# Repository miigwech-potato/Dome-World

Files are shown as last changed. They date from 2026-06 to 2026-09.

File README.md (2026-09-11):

# Cat Dome — a bermed, corbelled shelter with a wasp-cell wall

A printable test structure for the Canatara stage: small enough to build, cheap
enough to fail, and it tests the one thing the envelope claim depends on —
whether an unheated, self-ventilating, earth-sheltered shell stays liveable
through a Sarnia winter.

## What it is

- Interior: **440 mm diameter × 320 mm high**. Deliberately small. A cat heats
  the space with its own body; a large shelter is a cold shelter.
- Two openings, opposite each other, 150 mm wide. Cats will not use a shelter
  they can be cornered in.
- Wall: **5 mm skin + 16 mm hexagonal cell core + 5 mm skin = 26 mm.**
- Five corbelled tiers, eight segments each: **40 printed pieces** plus the
  chimney collar.
- Lower two tiers are bermed. The top three stand proud.

## The two findings that changed the design

**1. Print the segments flat, not standing.**

A dome printed in its final orientation has a near-horizontal apex — the top
tier came out at 64° of overhang and would need support. Laid flat on the bed,
each tier segment is a curved plate and the problem disappears. Every segment
fits within 200 × 200 mm.

This is also why the wall core is hexagonal cells rather than one continuous
air gap: laid flat, hex cell walls stand vertical on the bed and self-support.
A continuous cavity would sag.

**2. Do not put the wool in the cells.**

| core | R-value (m²K/W) | loss at ΔT=30K |
|---|---|---|
| air-filled cells | 0.692 | 13.2 W |
| wool-filled cells | 0.477 | 19.1 W |

Still air conducts at about 0.026 W/m·K. Wool is about 0.040. In a sealed 16 mm
cell the air is not convecting, so it is already the better insulator — packing
wool in makes the wall roughly 45% worse.

**Wool belongs on the inside face**, as a lining: contact comfort, moisture
buffering, and something to nest in. The cells stay empty.

## Does a cat heat it?

A resting cat produces roughly 8–15 W.

| ΔT | wall loss |
|---|---|
| 10 K | 4.4 W |
| 20 K | 8.8 W |
| 30 K | 13.2 W |
| 40 K | 17.6 W |

At ΔT = 30 K (−20 °C outside, +10 °C inside) the wall loses about what one cat
produces. That is marginal — and it is why the berm matters. Buried tiers see
soil temperature rather than air temperature, and in Sarnia that is the
difference between a ΔT of 30 and a ΔT of about 10.

**Berm the lower two tiers. The dome alone does not do it.**

## The chimney problem

A solar chimney moves air by making warm air leave. In August that is the whole
point — a litter space that does not ventilate is a space cats abandon.

In February it is a hole in the roof.

The collar takes a **plug**. Open through the warm months, closed through the
cold ones. If the plug is not there, the winter measurement will show the
envelope failing when what actually failed was the design of the chimney.

This is the first thing to instrument: temperature and humidity inside, with the
plug in and with it out, through one full year.

## Printing

- PETG or ASA. Not PLA — it creeps in sun and gets brittle below freezing.
- 0.3 mm layers, 3 perimeters, 15% infill on the skins.
- No supports needed if the segments are printed flat.
- Roughly 40 hours total across 40 pieces.
- Segments and tiers are numbered. Assemble from tier 0 up.

## What this stage does and does not test

**Tests:** whether the envelope holds temperature, whether ventilation keeps a
litter space liveable in August, whether the print survives a freeze-thaw cycle,
and whether animals given a free choice between this and a conventional
structure choose this one.

**Does not test:** human sanitation, which is the unsolved part and belongs on a
campus with plumbing twenty feet away, not in anybody's home.

## Files

- `catdome.scad` — parametric source. Change the numbers and re-render.
- `stl/tier0_seg.stl` … `stl/tier4_seg.stl` — one segment of each tier. Print
  eight of each.

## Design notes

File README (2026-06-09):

# Dome-World
just one of my ideas

Boozhoo // Bonjour // Hello my friend Premier Danielle Smith,
I would like to add one further note on so-called institutional neutrality for your consideration. I ask for grace if I am in any way unclear. In Ontario we are fluent in neither French nor inlgish, but I will do my best to get my point across with the language I have access to. Words are the first weapon which we reach for in a conflict, so I will draw mine out in the tradition of the "Irrepressible Letter Writer," Hidatsa leader Chief Wolf, who wrote persistently to successive presidents saying, "I wish to shake hands with the new Great Father," to demand that those who seek to govern his people look him in the eye before they would have him bow.
I speak from some personal familiarity with the machinery of institutional narrative. I was privileged to study corporate communication and public relations at Fanshawe College during the 2008 financial crisis, at a time when the Arab Spring first showed us how social media could be used to move masses of people and topple governments. As Occupy Wall Street rose up in response to reckless financial institutions and the institutions which were supposed to regulate them, I witnessed classmates set up tents and free libraries in Victoria Park and read their names in the news when the police came to shut it down. What stayed in my memory was the way that Occupy Wall Street's core calls for action were dismissed by the media as unrealistic simply because they had not been packaged in actionable administrative language. For this reason, the document which you are now reading arrives with appendixes, addendums, architectural principles, diagrams, and practical legislative steps. This correspondence is not a vague invitation to imagine a better world than we currently inhabit, but an announcement that the future we always dreamed possible has arrived in the flesh with specific proposals offered in a form that institutions can read. 
My submission is as follows:
Opening Letter — A reflection on institutional neutrality, professional regulation, and the historical context within which regulatory bodies claim authority, prompted by recent public debate regarding Peterson v. College of Psychologists of Ontario.
Appendix A: Flow-Core Framework — An interpretive systems framework offered as a lens for identifying bureaucratic inertia and delayed institutional feedback before crises cascade. It may complement existing analytical tools in areas including addiction services, mental health, and regulatory reform.
Appendix B: Children's Liberation and Dome-World Infrastructure — A legislative invitation to reconsider compulsory schooling frameworks, institutional claims on children's time, and community infrastructure design, with reference to established and proven education models (Montessori, Waldorf, Reggio Emilia) and Indigenous architectural traditions. Introduces the sheltered atrium as the architectural expression of Flow-Core principles.
Appendix C: Infrastructural Sovereignty — A legislative framework for decentralized, water-based hydraulic systems grounded in UP//DOWN gravitational storage, tendency settling, and Flow-Core Governance. Extends Dome-World principles from children's spaces to full community energy and resource autonomy.
Appendix D: Mental Health Transition and Relational Care — A legislative framework for transitioning Alberta's mental health system from a predominantly biomedical model toward relational, community-based care, with phased funding redistribution, informed consent standards, and Indigenous mental health sovereignty.
Appendix E: Ambient Cognition and AI Governance — An orientation to the governance challenges presented by distributed artificial intelligence systems, including the energy demands of AI infrastructure, specific risks warranting legislative attention (including cognitive warfare through personal channels), and principles for adaptive regulatory response.
Appendix F: Dual Justice and Legal Pluralism — A Flow-Core invitation to establish a parallel justice system administered by Treaty partners, addressing court backlogs, operationalizing genuine neutrality, and honouring the legal traditions that predate the Crown.
I write not as a representative of any organization, but as a constituent engaged in good faith with the philosophical and practical foundations of policy. The proposals offered are specific and actionable, and I have included citations and evidence throughout to support further review by the relevant ministries. I respectfully invite your office to direct the appropriate sections to the Ministries of Health, Education, Technology and Innovation, Indigenous Relations, Energy, Municipal Affairs, and Infrastructure as warranted by their respective mandates. I would welcome the opportunity for dialogue with any member of your team who wishes to explore these ideas further.

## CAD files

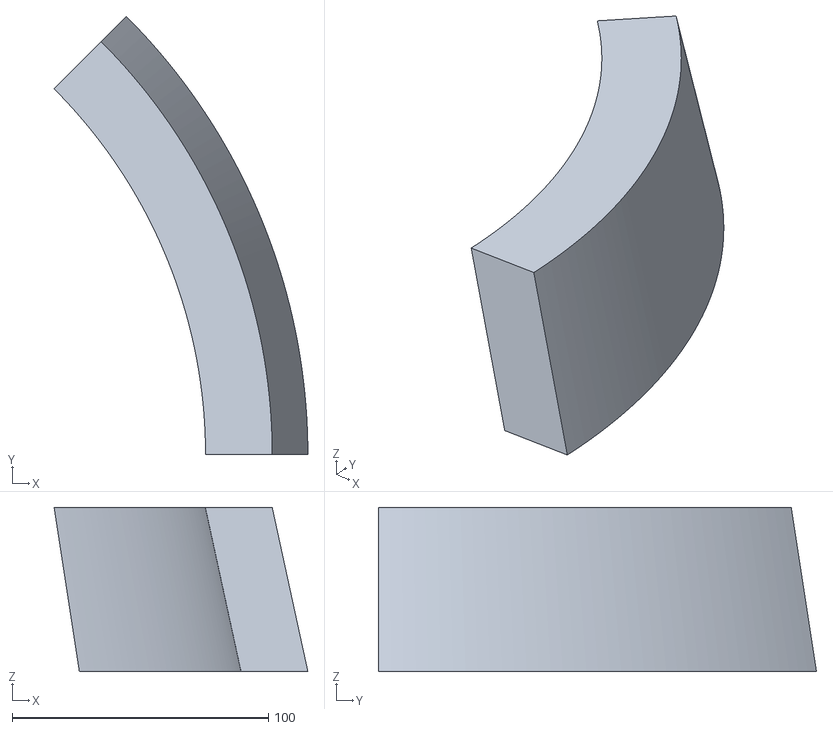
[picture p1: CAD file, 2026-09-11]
tier1_seg.stl
99.0 x 170.8 x 64.0

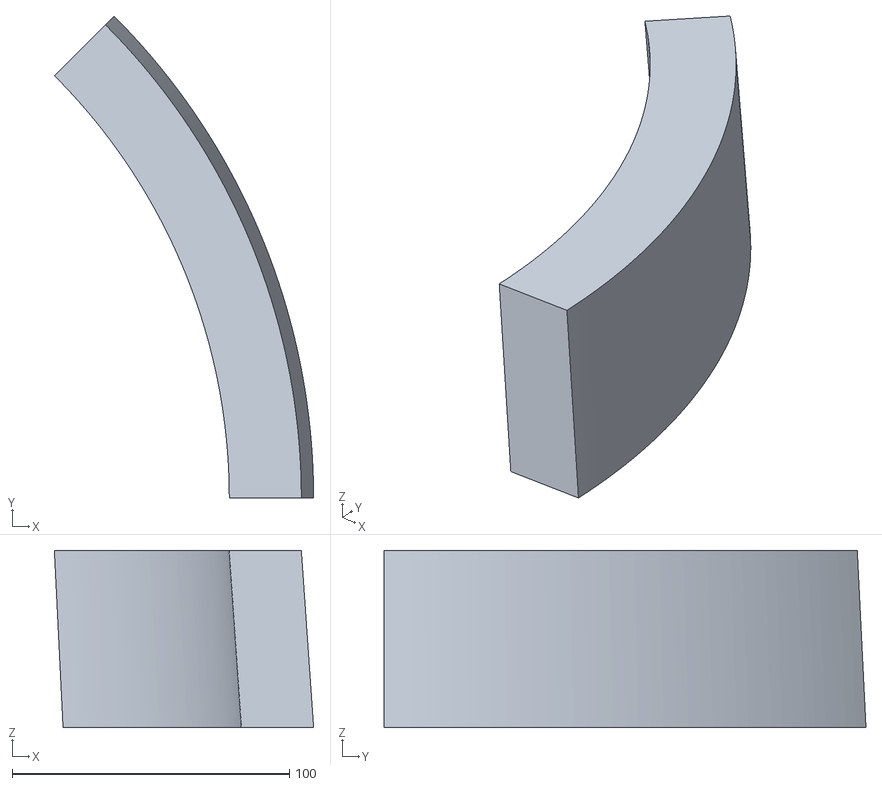
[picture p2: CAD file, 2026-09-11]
tier0_seg.stl
93.6 x 173.9 x 64.0

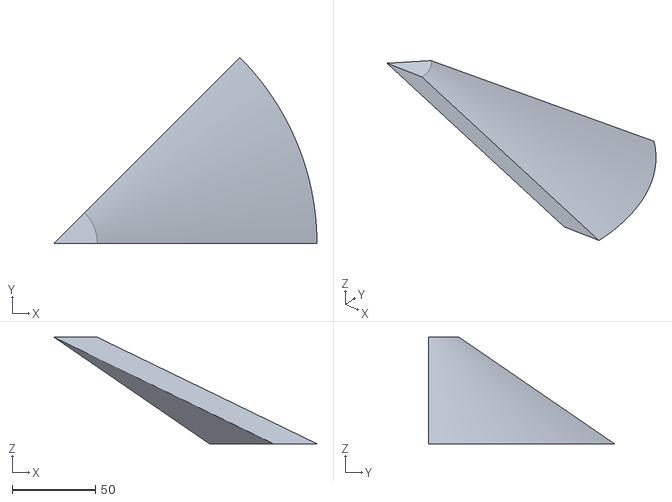
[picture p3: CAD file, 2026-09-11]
tier4_seg.stl
158.0 x 111.7 x 64.0

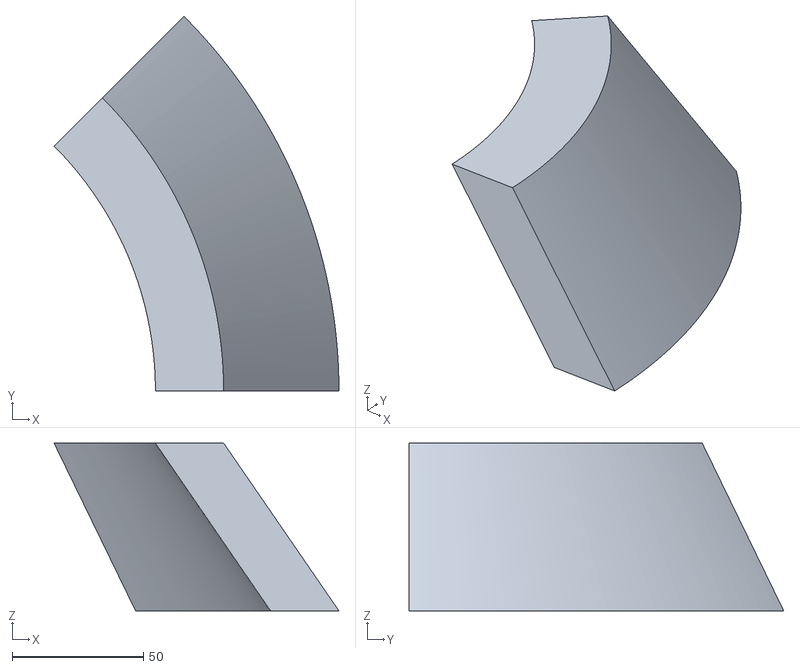
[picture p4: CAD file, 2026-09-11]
tier3_seg.stl
108.7 x 142.8 x 64.0

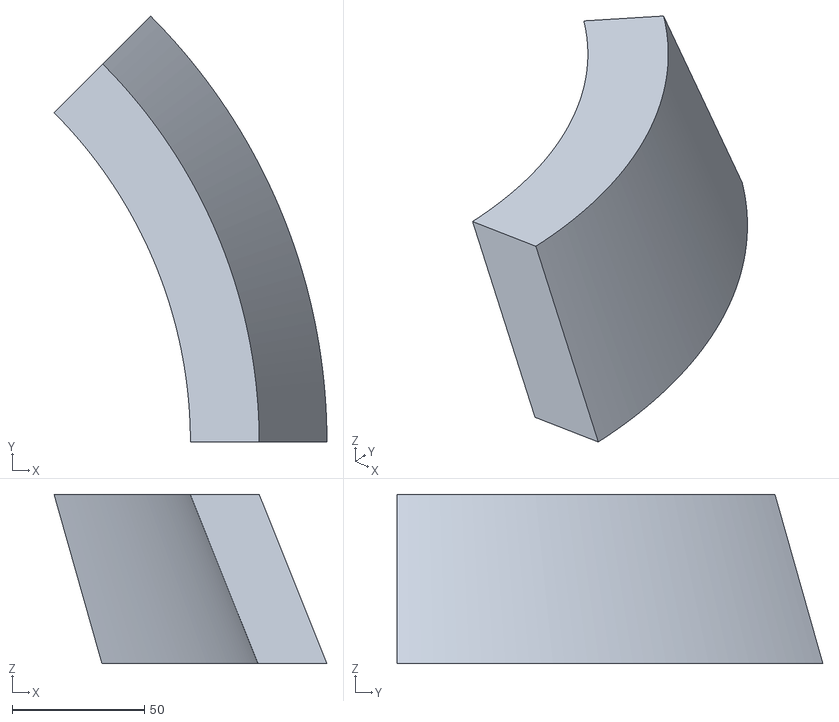
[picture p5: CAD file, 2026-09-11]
tier2_seg.stl
103.2 x 161.0 x 64.0

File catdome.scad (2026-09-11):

// CAT DOME - bermed, corbelled, wasp-cell wall
// Parametric source. Edit the parameters, render, export STL.
// Units: mm.  License: same terms as Dome-World.

R_IN    = 220;   // interior floor radius -> 440mm interior diameter
H_IN    = 320;   // interior apex height
SKIN    = 5;     // printed skin thickness
CORE    = 16;    // wasp-cell core depth (AIR, not wool - see README)
N_TIERS = 5;
N_SEG   = 8;
CELL    = 22;    // hex cell across-flats
CELLW   = 2;     // cell wall
CHIM_R  = 30;    // chimney bore radius
DOOR_W  = 150;   // entrance width
DOOR_H  = 165;   // entrance height
$fn     = 96;

WALL = SKIN + CORE + SKIN;

function r_in(z) = R_IN * sqrt(max(0, 1 - pow(min(z/H_IN,1), 2)));

module dome_shell() {
    rotate_extrude()
      polygon(concat(
        [for (i=[0:40]) let(z = H_IN*i/40) [r_in(z)+WALL, z]],
        [for (i=[40:-1:0]) let(z = H_IN*i/40) [r_in(z), z]]
      ));
}

module entrance() {
    translate([0,0,DOOR_H/2])
      rotate([90,0,0])
        union() {
          cube([DOOR_W, DOOR_H, 600], center=true);
          translate([0,DOOR_H/2,0]) cylinder(h=600, r=DOOR_W/2, center=true);
        }
}

module chimney_bore() {
    translate([0,0,H_IN-120]) cylinder(h=300, r=CHIM_R);
}

module tier(i) {
    z0 = H_IN*i/N_TIERS;  z1 = H_IN*(i+1)/N_TIERS;
    intersection() {
        difference() {
            dome_shell();
            entrance();
            translate([0,0,0]) rotate([0,0,180]) entrance();  // second exit
            chimney_bore();
        }
        translate([0,0,z0]) cylinder(h=z1-z0, r=R_IN+WALL+20);
    }
}

module segment(i, s) {
    intersection() {
        tier(i);
        rotate([0,0,s*360/N_SEG])
          linear_extrude(H_IN+10)
            polygon([[0,0],[600,0],[600*cos(360/N_SEG),600*sin(360/N_SEG)]]);
    }
}

// Render one piece at a time for export:
segment(0, 0);

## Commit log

2026-06-09 Add opening letter on institutional neutrality and authority
    Add an opening letter discussing the implications of institutional authority, neutrality, and the historical context of mental health regulation in relation to the case of Peterson v. College of Psyc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
2026-06-09 Add Appendix A: Flow-Core Framework Overview
    This appendix introduces the Flow-Core framework, exploring concepts of ambiance, memory, and the dynamics of meaning-making in relation to institutions and cognition. It emphasizes the importance of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
2026-06-09 Add framework for mental health system transition
    This appendix proposes a framework for transitioning Alberta's mental health system towards community-based care, emphasizing relational support and Indigenous sovereignty. It outlines current issues, principles for transition, and the impact on children, advocating for a shift from biomedical models to holistic approaches.
2026-06-09 Add Appendix C: Flow-Core Infrastructure Model
    This appendix presents a scalable infrastructure model based on Flow-Core principles, emphasizing decentralized hydraulic systems using water as the primary energy carrier. It outlines the core conce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
2026-06-09 Add Appendix E on Ambient Cognition Governance
    This appendix discusses the governance of ambient cognition, emphasizing the need for adaptive regulatory approaches and highlighting specific risks associated with centralized AI infrastructure. It 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
2026-06-09 Propose pilot framework for legal pluralism in Alberta
    This appendix proposes a pilot framework for legal pluralism in Alberta, addressing the limitations of the Regulated Professions Neutrality Act and advocating for the inclusion of Indigenous legal traditions in the province's professional regulatory framework. It outlines the problems, opportunities, and a proposed pilot for a parallel justice system that respects Treaty relationships.
2026-06-11 Revise Appendix C for children's liberation model
    This appendix presents a comprehensive model for children's liberation through decentralized, gravity-based hydraulic systems, emphasizing relational design and community engagement. It critiques exi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
2026-06-15 Add Appendix D: Infrastructural Sovereignty Framework
    This appendix outlines a decentralized, gravity-based hydraulic infrastructure model for Dome-World, emphasizing energy independence and community resilience. It details the core concepts, proposed p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
